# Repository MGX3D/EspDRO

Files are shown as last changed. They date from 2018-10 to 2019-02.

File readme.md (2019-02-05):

EspDRO - ESP32 DIY Digital Readout
----

EspDRO reads and proxies data from SPC capable (serial) digital calipers and indicators without any additional electronic components but using instead the built-in ADC in ESP32. It enables building custom, high-resolution measuring instruments, fully capable DRO (Digital Readout) panels for CNC/3D Printers, upgrade open-loop robots to closed-loop, point cloud 3D scanners, etc.

It costs $10-$20 to build (excluding instruments and time) and it's only 500 lines of code - it's amazing how powerful and affordable IoT chips (like ESP32) have become. 

Overview:
---
- Reads and re-transmits the instrumet data over multiple channels:
    - **WebSockets broadcasting**: allows building simple, low latency clients (10 lines of code Python sample [PyDRO](examples/PyDRO/) included as well as JavaScript/HTML [jsDRO](/examples/jsDRO) )
    - **Built-in web server**:  allows reading the data from browser/phone/tablet without any additional apps. Big display!
    - **REST APIs** and mDNS support: to build thin client apps easily
    - **USB serial**: for running without WiFi
        
- Protocol and interfacing:
    - ESP32 reads the 1.5V SPC signal via the ADC in ESP32, therefore **no additional level shifting electronic components necessary**
    - **Automatic baud rate**: it reads as fast as the instrument can transmit, in practice however most cheap devices seem to send packets at 8-10Hz
    - **Built-in 4KB buffer** for historical reads - easy to extend if there is free memory on the chip
    - Data is read on a separate thread to avoid packet loss (can be moved on a different CPU core in ESP32)

- Other (fine touches):
    - **Automatic Access Point -> Client mode**: Includes WiFi setup page and saves credentials in EEPROM, so it does not need to be reflashed when going to a different location
    - **Automatic units conversion**: EspDRO works only with microns internally which means readings remain constant even if you change the units SAE<->metric while you measure. Keeps things simple.
    - **Self-documented Pinout**: for those instances when wires come loose and memory doesn't help
    - **mDNS advertising**: allows instrument names to be decoupled from knowing IP address
    - **3D Printable SPC connector** ([also onthingiverse](https://www.thingiverse.com/thing:3141366)): 
        - All you need is 3 wires to make a SPC connector (4 wires if you want to power the instrument from ESP32, example using AMS1117 1.5v voltage regulator)
        - Tested to work on both calipers and indicators (slightly different commercial connectors).

**Web view**

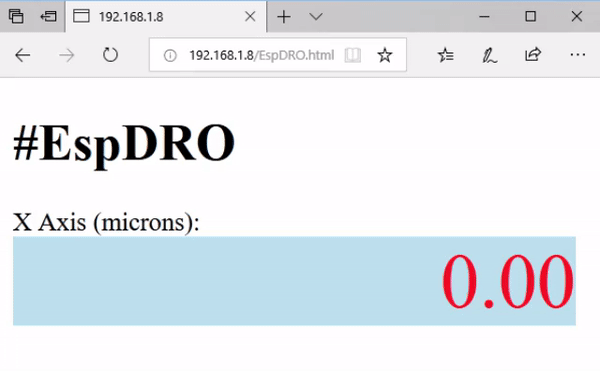
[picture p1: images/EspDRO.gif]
EspDRO


**Schematic**

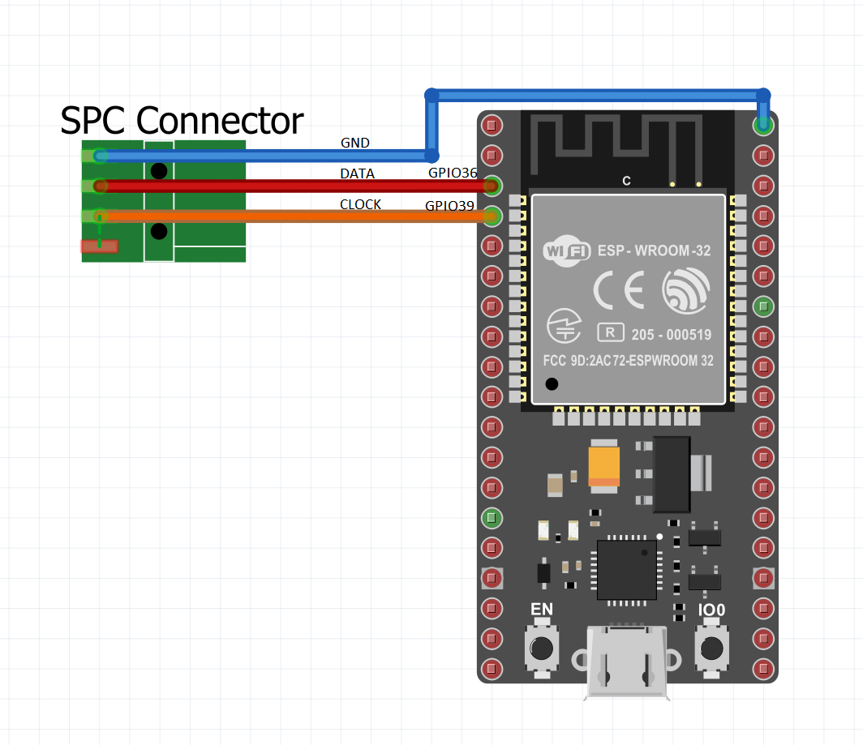
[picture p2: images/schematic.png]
schematic


**Video of it in action**

video (https://www.youtube.com/watch?v=P8z91OxXOTo)

Background:
----
This project started with my need to diagnose the positioning errors in one of my 3D printers: I had both 1-micron and 10-micron resolution indicators and calipers but measuring manually (write down readings from the instrument LCD) would have taken way too much time and effort. Since I had an ESP32 laying around, I figured I'd give that a try and I was amazed how easy it was to automate the whole thing: command the 3D printer via G-Code, then read the calipers/indicator via ESP32. Of course that in the process of building the instrument people seeing the data started asking for the firmware, so I decided to put some "finishing touches" (yeah, that really means 10x more lines of code :) ) and publish it, but also as a PIF for others that have posted useful guides around this space and helped me build this quickly. That's how #EspDRO came up.

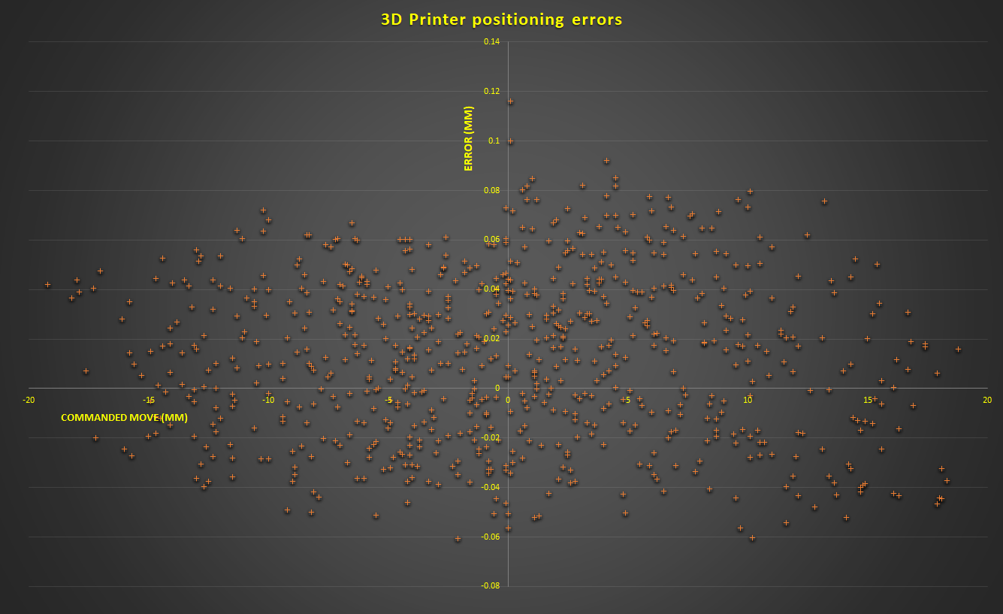
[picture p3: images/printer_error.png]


Installation:
----
_Software prerequisites_:

Arduino IDE (1.8.6) with [ESP32 support](https://github.com/espressif/arduino-esp32), including [esp32fs filesystem uploader plugin](https://github.com/me-no-dev/arduino-esp32fs-plugin) 

_Hardware prerequisites_:
- Espressif ESP32. The particular board this firmware was developed with is this (if yours is different, adjust dataPin and clockPin in the source): 
    - 
- SPC serial cable: if you don't have one you can use the [3D printable connector](CAD/spc_connector.stl), see [thingiverse page](https://www.thingiverse.com/thing:3141366) for more info. 
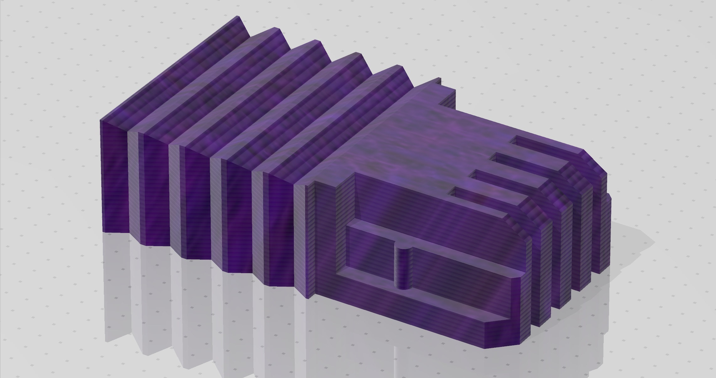
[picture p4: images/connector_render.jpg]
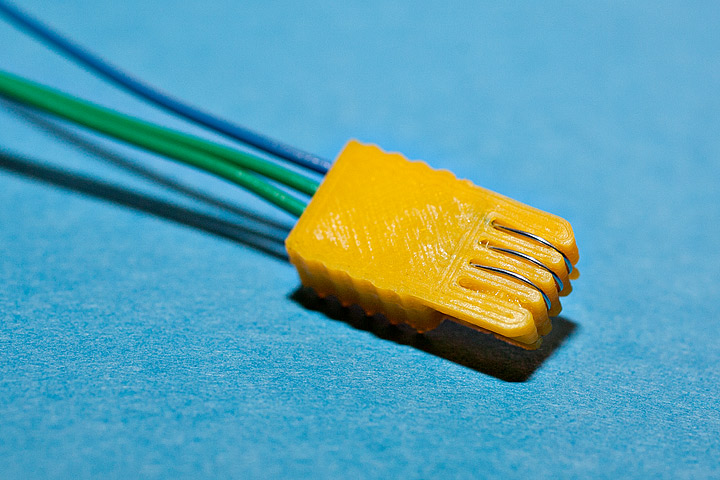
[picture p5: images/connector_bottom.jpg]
    -  
- Digital scale, calipers or DRO matching the connector. Examples:
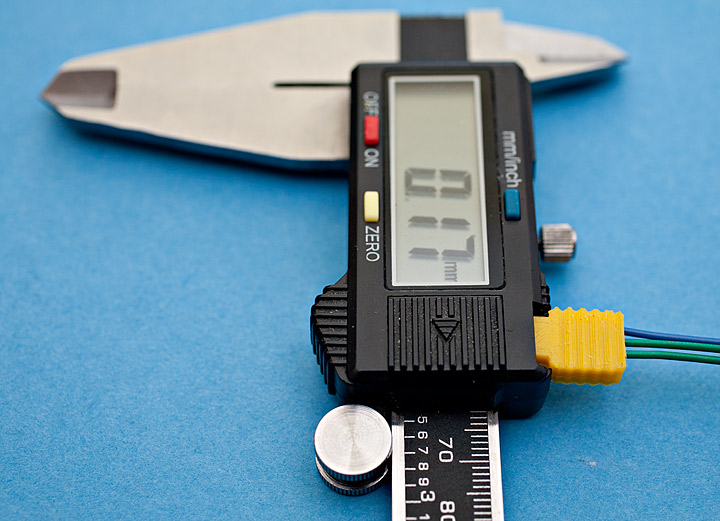
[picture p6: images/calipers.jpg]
caliper
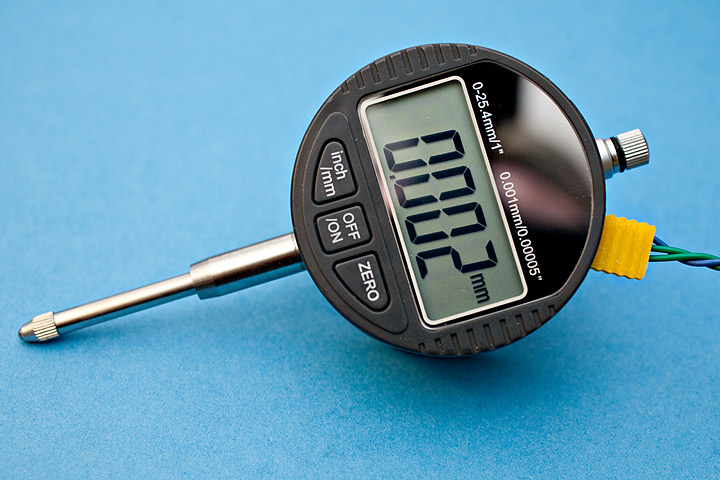
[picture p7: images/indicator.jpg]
indicator
    -  

Validate the cable works and the pinout in the firmware is correct. If you have an oscilloscope, the signal should look like this:
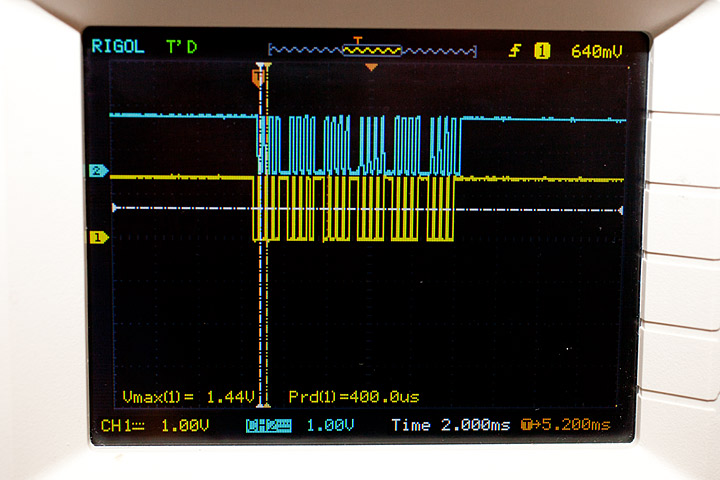
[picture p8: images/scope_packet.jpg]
scope packet
- 

Flash the webserver files (Tools->ESP32 Sketch Data Upload) and then upload the sketch/firmware. Start the serial monitor and you should see something like this:
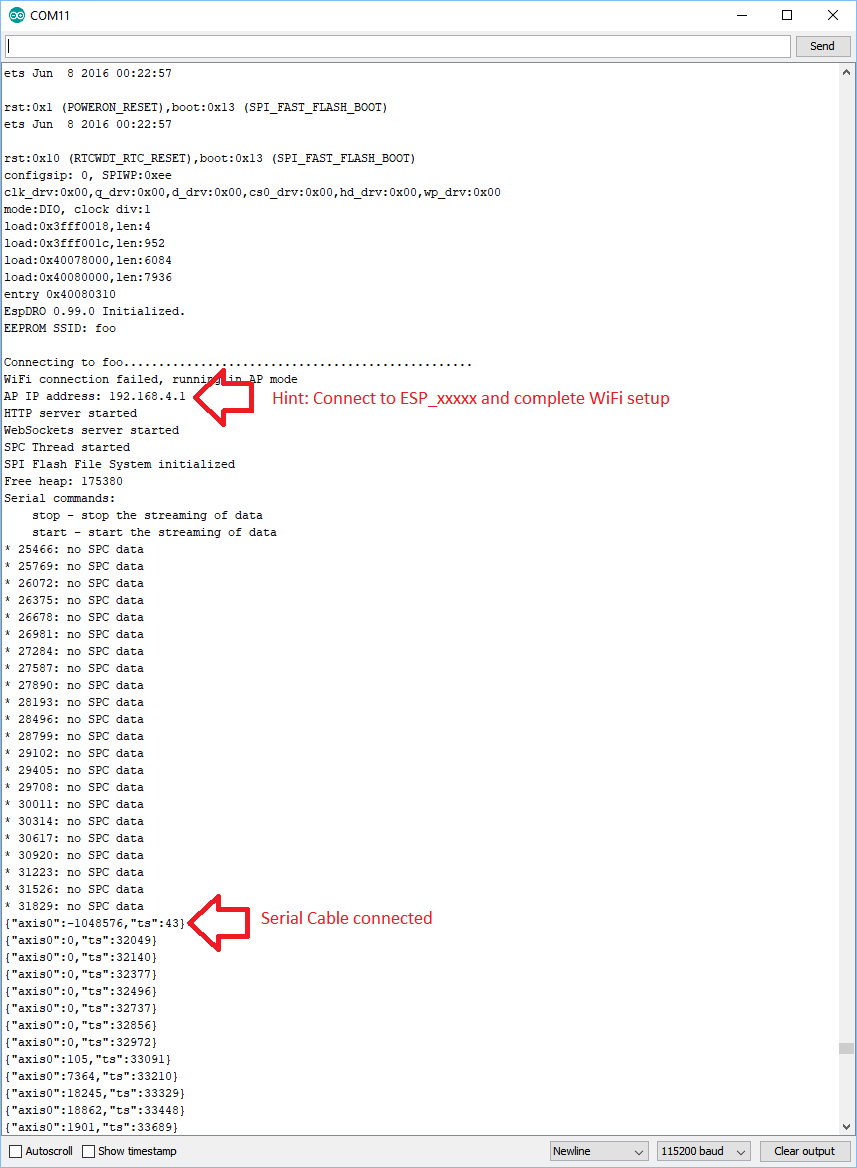
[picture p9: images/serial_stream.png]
serial monitor
- 

Note: If you don't have an oscilloscope and the data is not coming through, there is a 'debug' serial command which you can use to calibrate the Analog Digital Converter. This will also tell you if the pins on ESP32 are actually getting any analog data, as different dev boards have the ADC1_0 and ADC1_3 pins mapped differently than DevKitC above.

Now navigate to the main page and set up WiFi:
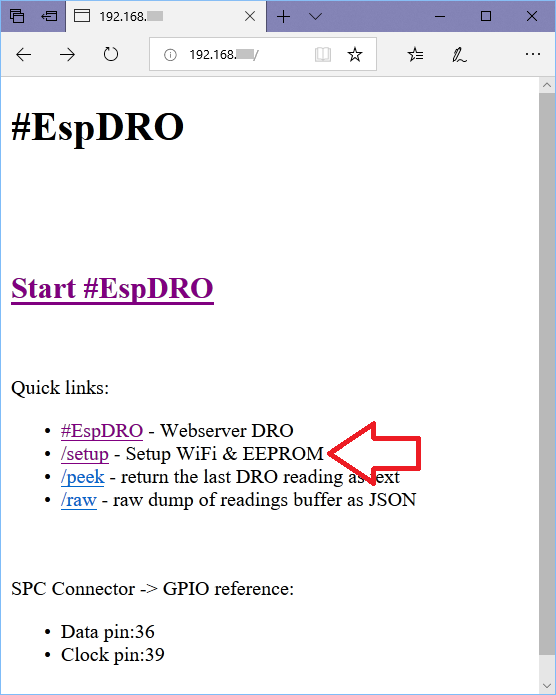
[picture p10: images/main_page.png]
main page
- 
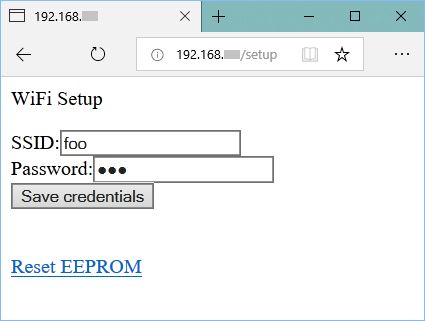
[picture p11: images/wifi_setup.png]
wifi setup
- 

Future plans (opportunities for contributors):
---
- **Multi-Axis**: Currently only one instrument supported but it's possible to extend EspDRO to multi-axis ($TODO, soon)
- **Time-of-Flight sensors**: One thing I'm really eager to add is [VL53L0X](https://www.st.com/resource/en/datasheet/vl53l0x.pdf) Time-of-Flight sensor, this should be able to read at 15-50Hz and +/-3% accuracy and without touching (influencing) the measured object. 
- **TTL glass scale**:  these are more expensive devices used in large mill DROs and can have 0.5-5 microns accuracy and extreme lengths (1+ meters)
- **Mill DRO functions**: implement common functions in DRO (find mid-point, center of circle, create hole patterns, datum points, absolute/incremental, memory, units conversion, etc)
- **Live charting**: 1-3 axis charting directly built-in the web console: for example to build a print bed mesh map (or 2.5D/3D point cloud) or axis error scatter plot 
- **Bluetooth support**: since ESP32 has BT, why not add a 5th interface?
- **Digital micrometer support**: Dicfeos and similar are affordable and micron-level accuracy - connector is different and can't be 3D printed. Less of a priority, as these require manual operation to measure.

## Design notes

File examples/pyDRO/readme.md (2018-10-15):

Sample Python client for EspDRO

It reads the data via websocket and prints it on console.

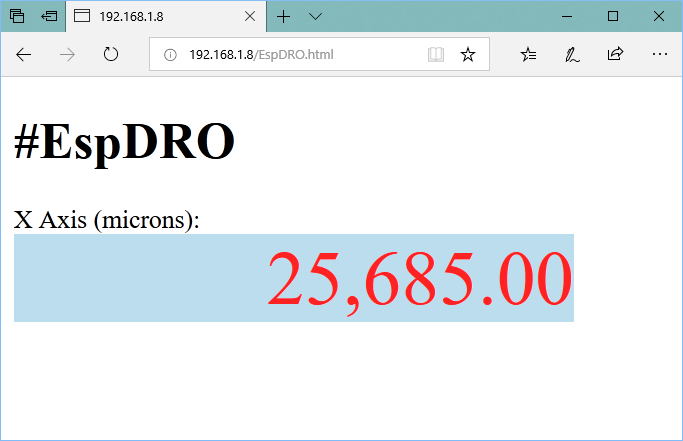
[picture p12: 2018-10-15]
images/esp_dro.png

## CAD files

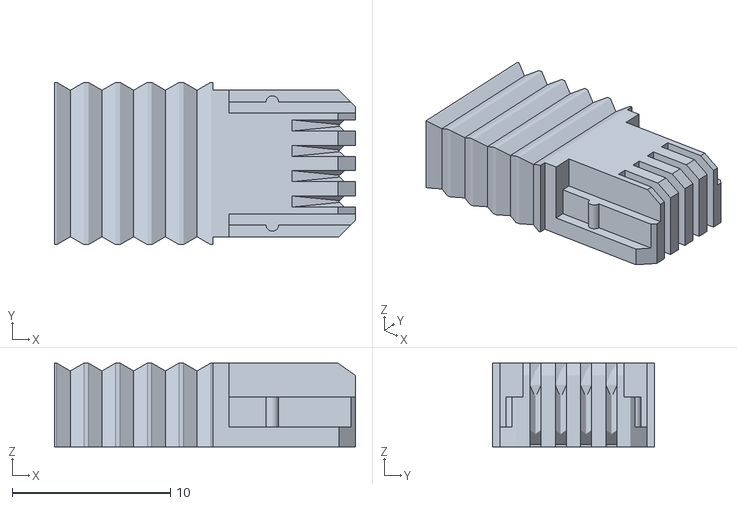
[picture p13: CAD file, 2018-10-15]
CAD/spc_connector.stl
19.0 x 10.2 x 5.30

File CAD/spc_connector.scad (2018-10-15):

// SPC serial connector wire guide. 
// Design by Marius Gheorghescu, Oct 2018
//
// Suggested print settings: flexible filament, 0.15mm layer height
//

// bottom to top
top_height = 5.3;
top_width = 6.4;

clip_height = 3.15;
clip_width = 7.75;

base_height = 1.25;
base_width = 9.25;

connector_depth = 8;

retention_clip_depth = 2.75;
retention_clip_radius = 0.4;

epsilon = 0.001;

pin_spacing = 1.6;

pin_depth = 0.5;
pin_width = 0.75;

pin_spacing_connector = 2.6;

module wire_connector()
{
    wire_dia_coated_x = 1.2;
    wire_dia_coated_z = 1.4;
    wire_dia = 0.7;
    wire_spacing_factor = 1.3;
    
    grip_depth = 10;
    
    difference() {

        $fn = 30;
        
        union() {
            
            // base
            translate([connector_depth/2,0,base_height/2])
                cube([connector_depth, base_width, base_height], center=true);

            // grip
            translate([-grip_depth/2 - 1,0, top_height/2])
                cube([grip_depth, base_width+1, top_height], center=true);
            
            translate([-grip_depth/2,0, top_height/2])
                cube([grip_depth, base_width, top_height], center=true);
            
            // mid-point block
            translate([connector_depth/2,0,clip_height/2])
                cube([connector_depth, clip_width, clip_height], center=true);

            // top block
            translate([connector_depth/2,0,top_height/2])
                cube([connector_depth, top_width, top_height], center=true);
            
            // retention clips
            color("red")
            translate([retention_clip_depth, clip_width/2, clip_height/2])
                cylinder(r=retention_clip_radius, h=clip_height, center=true);

            color("red")
            translate([retention_clip_depth, -clip_width/2, clip_height/2])
                cylinder(r=retention_clip_radius, h=clip_height, center=true);
        }
        
        // see-through cut-out
        // translate([-10,-10,0]) cube([20,20,20], center=true);

        // front chamfer 
        rotate([0,35,0])
        translate([connector_depth/2,0,top_height + top_height/2 + 1])
            cube([connector_depth, top_width+epsilon, top_height/4], center=true);
        

        // chamfer corners
        {
            translate([connector_depth, base_width, top_height/2 - epsilon])
            rotate([0,0,45])
            cube([connector_depth, base_width, top_height], center=true);

            translate([connector_depth, -base_width, top_height/2 - epsilon])
            rotate([0,0,-45])
            cube([connector_depth, base_width, top_height], center=true);
        }        

        // ribs
        for(i=[1:2:grip_depth]) {
            translate([-1-i,-base_width/2-1,top_height/2])
                rotate([0,0,-30])
                cylinder(r=1, h=top_height+epsilon, $fn=6, center=true);

            translate([-1-i,base_width/2+1,top_height/2])
                rotate([0,0,30])
                cylinder(r=1, h=top_height+epsilon, $fn=6, center=true);


            translate([-1-i,0,top_height+0.5])
            rotate([0,90,90])
                cylinder(r=1, h=base_width+2, $fn=6, center=true);
        }

        // pin contact area guide
        // translate([connector_depth - 2.45,0,0])%cube([2.40, 5.54, 1], center=true);
        
        for(i=[-1.5:1:1.5]) {

            // contact channels
            #translate([connector_depth/2, i*pin_spacing, 0])
                cube([connector_depth/2, pin_width, pin_depth], center=true);

            // top attach
            hull() {
            translate([connector_depth*0.75, i*pin_spacing, top_height - wire_dia_coated_z/2 + epsilon])
                cube([connector_depth/2, wire_dia, wire_dia_coated_z], center=true);

            translate([connector_depth*0.75, i*pin_spacing, top_height - wire_dia_coated_z/2 + epsilon])
                rotate([0,25,0])
                cube([connector_depth/2, 0.01, wire_dia_coated_z], center=true);
            }

            // slicer path width guide
            //translate([0, -top_width/2 + 0.2,0])
            //%color("blue", 0.2) cube([20, 0.4, top_height*1.5], center=true);

            // through wires
            translate([-connector_depth - epsilon, i*pin_spacing*wire_spacing_factor, top_height/2])
                cube([connector_depth, wire_dia_coated_x, wire_dia_coated_z], center=true);

            // front contact lift 
            translate([connector_depth - 1, i*pin_spacing, pin_depth/2 - epsilon])
                rotate([0,-35,0])
                cube([connector_depth, wire_dia, 2*pin_depth], center=true);

            // wire front channel
            hull() {
                translate([connector_depth - wire_dia/2 + epsilon, i*pin_spacing, 0])
                    cube([wire_dia, wire_dia, wire_dia], center=true);

                hull() {
                    translate([connector_depth - wire_dia/2 + epsilon, i*pin_spacing, top_height/2])
                        cube([wire_dia, wire_dia, top_height], center=true);
                    translate([connector_depth - wire_dia/2 + epsilon, i*pin_spacing, top_height/2])
                        cube([wire_dia*2, 0.01, top_height], center=true);
                }
            }

            // back
            #hull() {
                translate([connector_depth/2, i*pin_spacing, 0])
                    cube([2*wire_dia, wire_dia, wire_dia], center=true);

                translate([-connector_depth/2, i*pin_spacing*wire_spacing_factor, top_height/2])
                    cube([wire_dia_coated_x, wire_dia_coated_x, wire_dia_coated_z], center=true);
            }

        }
    }
}

color("green")
    wire_connector();

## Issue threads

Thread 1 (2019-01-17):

Logging AP IP adress

pwe101, 2019-01-17:
Hi,
The logging of the AP IP adress does not work correctly, the code:
log("AP IP address: %s", WiFi.softAPIP().toString());
results in:
AP IP address: ⸮8⸮?
in the serial monitor

Adding
Serial.println(WiFi.softAPIP());
to the code does give a valid IP address.

Serial.println(WiFi.softAPIP().toString());
Also gives a valid IP address.

Closed 2019-01-19.

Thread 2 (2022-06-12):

ESPRO at 50Hz in stead of 3Hz

jeedee23, 2022-06-12:
This is a very nice project, and I was wondering if anyone has developed the 'FAST' mode DRO.
My plan is to use this DRO as a closed-loop system to drive spindles at a determined speed, the feedback of 50Hz or faster would be ok, but the feedback of 3 Hz is too slow.

The 50Hz functionality is already built-in in all of these calipers by means of the hidden 'mode' button: Activating the mode button switches back and forth between fast reading and regular reading modes.  The scale updates about every 20ms (50 Hz) in fast reading mode instead of every 300ms (3 Hz).
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

Personally I would an interrupt to determine the 'getpacket' (which waits until the packet is completed by the getbit() function) . This means that the PACKET_READ_TIMEOUT would not matter anymore, since the complete packet is captured.  (it would have a purpose still to use it of course, but the value would be around 20 ms)
Then I would compare the new packet with the two previous ones to inspect for glitches
Then use ESPNOW to send the data to another MAINESP32 which takes care of the readout and send through the server, since the process would be to fast now, to be concerned with the whole handshaking, acknowledging etc.

The DROX-esp3E2 (X axis) DROY-esp32(Y-axis) would then adapt the position/speed they received from MAINESP32.

Somebody gone this far already?

MGX3D, 2022-06-12:
Interesting, I didn't know about this mode but it should be possible: ESP32 has a fast ADC mode via I2S, so it can go to 200KHz or more. It also have super high resolution (and low drift) clocks and timers via MCPWM if needed, but afaik (unlike STM32) the two cannot be synchronized on ESP32 (except by means of software tricks)

jeedee23, 2022-06-12:
Hi Marius,

Did not really understand what you mean. You mean the speed of readout or the speed for adjusting speeds (a sort of PID at first) following the readout.

We read the whole packet in a timespan of 20 ms (your PACKET_READ_TIMEOUT 250 ms )  the 'long' low time before and after the stream of bits not included. Changing the milliseconds to microseconds would be one of the first things to do.
After that, we need to use the time left to adjust speed and position of the spindle (once a PID is established, those values can be stored or transmitted at boot by the main computer (where the DRO will be displayed and the code is running giving the positions to go to). This it totally unlike steppers doing xxx steps to go to a position, no, it's giving a position and 'be there at that time at that speed'. By that means any motor can be used, supposed the resolution/speed/reaction time is physically possible, Th be clear, in this first setup, I'll be using DC gear motors with encoders (for redundancy, and also for backlash elimination)

I2S: you mean I2C?
Finally I would use one core of the ESP32 for readout and ESPNOW, the other one for motor control, they can work independently, so it should be perfectly possible.

I just don't know how to setup everything in microseconds, if you could give me a hint there, that would be a charm.

Oh yes, I rebuilt the calipers so they can read up to 1999,99 mm, ordered enough pcb (behind the masking tape, for 100 of those calipers)

Sartos, 2024-09-29:
> Ах да, я переделал штангенциркули так, чтобы они могли считывать показания до 1999,99 мм, заказал достаточно печатной платы (под малярной лентой, для 100 таких штангенциркулей)

Hello Johan. Could you tell me how to modify the calipers so that they read such large readings?

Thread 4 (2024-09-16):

randomic data

GlidLov, 2024-09-16:
Hi,

i've setup an esp32 with EspDRO as showed in readme (pins 36 and 39, and GND) with a standard  chinese 150mm caliper with the interface plug, and all i'm getting is randomic data. I tried to unplug and swapping pins with no success. Debug prompt shows data arrives, but numbers appears random, even when caliper is not moving at all.
What can i try? Do other ADC on esp32 works aswell?

PS i converted the SPIFF code into LittleFS code (trivial) since spiffs is not supported anymore. It works ok just swapping libs and changing SPIFFs occurrences.

Aleitao2, 2025-01-13:
Hello,
I am trying to implement that code. It runs smoothly, but I am getting random values as well. Did you find a solution? What hardware are you using, and how are you powering the caliper?
Did you use a level shifter for the data and clock signals?

In my case, I am using a resistor voltage divider and connecting the CLK and DAT pins directly to the ESP GPIOs 33 and 32.

I am using Arduino IDE v1.8.13, which allows you to use a tool to burn the data content. The tool I mentioned : https://github.com/me-no-dev/arduino-esp32fs-plugin

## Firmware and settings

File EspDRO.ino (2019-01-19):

#include <WiFiClient.h>
#include <WiFi.h>
#include <EEPROM.h>
#include <WebServer.h>
#include <ESPmDNS.h>
#include <WebSockets.h>
#include <WebSocketsServer.h>
#include <driver/adc.h>
#include <FS.h>
#include "SPIFFS.h"

#define ESPDRO_VERSION "0.99.1"

// WiFi configuration - can be changed via AP/EEPROM
const char* ssid = "EspDRO";
const char* password = "EspDRO";

// Note: this sketch requires the webserver files to be uploaded to ESP32 SPIFFS, see: https://github.com/me-no-dev/arduino-esp32fs-plugin

// Pin Configuration - !!! Update This !!! 
// Example pinout: https://raw.githubusercontent.com/gojimmypi/ESP32/master/images/myESP32%20DevKitC%20pinout.png
int dataPin = 36; // yellow
int clockPin = 39; // green

// ADC threshold for 1.5V SPCsignals (at 6dB/11-bit, high comes to around 1570 in analogRead() )
#define ADC_TRESHOLD 800

// define this to display the raw signal (useful to troubleshoot cable or signal level issues)
#define DEBUG_SIGNAL 0

// timeout in milliseconds for a bit read ($TODO - change to micros() )
#define BIT_READ_TIMEOUT 100

// timeout for a packet read 
#define PACKET_READ_TIMEOUT 250

// Packet format: [0 .. 19]=data, 20=sign, [21..22]=unused?, 23=inch
#define PACKET_BITS       24

// minimum reading
#define MIN_RANGE -(1<<20)

// DRO circular buffer entries (4096 entries is roughly the equivalent of 8 minutes of data)
#define DRO_BUFFER_SIZE  0x1000


// DRO 1-Reading class
struct Reading
{  
    uint32_t timestamp;
    int32_t microns;

    Reading(): timestamp(millis()), microns(MIN_RANGE)  {}

    Reading& operator=(const Reading& obj) {
      timestamp = obj.timestamp;
      microns = obj.microns;
      return *this;
    }    
};


// DRO circular buffer
Reading dro_buffer[DRO_BUFFER_SIZE] = {};
size_t dro_index = 0;

unsigned char eepromSignature = 0x5A;

bool client_mode = 1;
bool stream_mode = 1;
volatile bool debug_mode = 0;

WebServer server(80);
WebSocketsServer webSocket = WebSocketsServer(81);

void log(char *fmt, ... )
{  
  char buf[128];
  va_list args;
  va_start (args, fmt);
  vsnprintf(buf, 128, fmt, args);
  va_end (args);
  Serial.println(buf);
}

// capped read: -1 (timeout), 0, 1
int getBit() {
    int data;

    if (debug_mode) {
      // debug code to sample the data reads
      log("CLK:%6d DATA:%6d\n", analogRead(clockPin), analogRead(dataPin));
    }
        
    int readTimeout = millis() + BIT_READ_TIMEOUT;
    while (analogRead(clockPin) > ADC_TRESHOLD) {
      if (millis() > readTimeout)
        return -1;
    }
    
    while (analogRead(clockPin) < ADC_TRESHOLD) {
      if (millis() > readTimeout)
        return -1;
    }
    
    data = (analogRead(dataPin) > ADC_TRESHOLD)?1:0;
    return data;
}

// read one full packet
long getPacket() 
{
    long packet = 0;
    int readTimeout = millis() + PACKET_READ_TIMEOUT;

    int bitIndex = 0;
    while (bitIndex < PACKET_BITS) {
      int bit = getBit();
      if (bit < 0 ) {
        // bit read timeout: reset packet or bail out
        if (millis() > readTimeout) {
          // packet timeout
          return -1;
        }
        
        bitIndex = 0;
        packet = 0;
        continue;
      }

      packet |= (bit & 1)<<bitIndex;
      
      bitIndex++;
    }
    
    return packet;
}

// convert a packet to signed microns
long getMicrons(long packet)
{
  if (packet < 0)
    return MIN_RANGE;
    
  long data = (packet & 0xFFFFF)*( (packet & 0x100000)?-1:1);

  if (packet & 0x800000) {
        // inch value (this comes sub-sampled) 
        data = data*254/200;
  }

  return data;
}


void spcTask( void * parameter )
{
    uint32_t lastReadTime = millis();

    for(;;) { 
      long packet = getPacket();
      
      if (packet < 0) {
        // read timeout, display?
        if (millis() > lastReadTime + PACKET_READ_TIMEOUT) {
          // advance last read to time-out
          lastReadTime = millis();
          log("* %d: no SPC data", lastReadTime);
        }
      } else {

        // add to local queue
        //log("* %d: microns=%d raw=0x%08X", millis(), getMicrons(packet), packet);
        size_t new_dro_index = (dro_index+1) % DRO_BUFFER_SIZE;
        dro_buffer[new_dro_index].timestamp = millis();
        dro_buffer[new_dro_index].microns = getMicrons(packet);
        dro_index = new_dro_index;

        // broadcast to all websocket clients
        char buf[128];
        sprintf(buf, "{\"axis0\":%d,\"ts\":%d}", dro_buffer[new_dro_index].microns, dro_buffer[new_dro_index].timestamp);
        webSocket.broadcastTXT(buf);
      }
    } 
    //vTaskDelete( NULL ); 
}

void webSocketEvent(uint8_t num, WStype_t type, uint8_t * payload, size_t length) {

    switch(type) {
        case WStype_DISCONNECTED:
            log("[%u] Disconnected!\n", num);
            break;
            
        case WStype_CONNECTED:
            {
                log("[%u] Connected from %s url: '%s'\n", num, webSocket.remoteIP(num).toString().c_str(), payload);

                // send message to client
                webSocket.sendTXT(num, "Connected");
            }
            break;
            
        case WStype_TEXT:
            log("[%u] get Text: %s\n", num, payload);

            // send message to client
            // webSocket.sendTXT(num, "message here");

            // send data to all connected clients
            // webSocket.broadcastTXT("message here");
            break;
            
        case WStype_BIN:
            log("[%u] get binary length: %u\n", num, length);

            // send message to client
            // webSocket.sendBIN(num, payload, length);
            break;
            
    case WStype_ERROR:      
    case WStype_FRAGMENT_TEXT_START:
    case WStype_FRAGMENT_BIN_START:
    case WStype_FRAGMENT:
    case WStype_FRAGMENT_FIN:
      break;
    }

}

// root HTTP request - keep this in code in case there is any SPIFFS corruption
void handle_root() {
  String content = "<!DOCTYPE HTML>\r\n<html><body>";
  content += "<h1>#EspDRO</h1><br>";
  content += "<br><br><h2><a href=\"/EspDRO.html\">Start #EspDRO</a></h2><br><br>";
  content += "Quick links: <ul>";
  content += "<li><a href=\"/EspDRO.html\">#EspDRO</a> - Webserver DRO</li>";
  content += "<li><a href=\"/setup\">/setup</a> - Setup WiFi & EEPROM</li>";
  content += "<li><a href=\"/peek\">/peek</a> - return the last DRO reading as text</li>";
  content += "<li><a href=\"/raw\">/raw</a> - raw dump of readings buffer as JSON</li>";
  content += "</ul><br>";  
  content += "<br>SPC Connector -> GPIO reference:<br><ul><li>Data pin:" + String(dataPin) + "</li><li>Clock pin:" + String(clockPin) + "</li></ul><br>";
  content += "</body></html>";
  
  server.send(200, "text/html", content);
  delay(50);
}

// SPIFFS content type autodetect
String getContentType(String filename)
{
  if (filename.endsWith(".html")) return "text/html";
  else if (filename.endsWith(".css")) return "text/css";
  else if (filename.endsWith(".js")) return "application/javascript";
  else if (filename.endsWith(".png")) return "image/png";
  else if (filename.endsWith(".jpg")) return "image/jpeg";
  else if (filename.endsWith(".ico")) return "image/x-icon";
  return "text/plain";
}

// serve SPIFFS requests
bool handleFS(String path)
{
  if (SPIFFS.exists(path)) {
    File file = SPIFFS.open(path, "r");
    server.streamFile(file, getContentType(path));
    file.close();
    return true;    
  }
  log("Error in SPIFFS request: '%s", path.c_str());
  return false;
}

void setup()
{
  pinMode(dataPin, INPUT);     
  pinMode(clockPin, INPUT);

  EEPROM.begin(512);
  delay(20);

  Reading start_reading;
  dro_buffer[dro_index] = start_reading;

  Serial.begin(115200);
  log("EspDRO %s initialized.", ESPDRO_VERSION);

  analogReadResolution(11);
  
  analogSetAttenuation(ADC_6db);
  adc1_config_width(ADC_WIDTH_BIT_10);

  String essid = ssid;
  String epassword = password;
  
  if (client_mode) 
  {
    // attempt WiFi client mode
    essid = "";
    epassword = "";

    if (EEPROM.read(128) != eepromSignature) {
      log("EEPROM not initialized");
    } else {
      for (int i = 0; i < 32; ++i)
      {
        essid += char(EEPROM.read(i));
      }
      
      log("EEPROM SSID: %s", essid.c_str());
      for (int i = 32; i < 96; ++i)
      {
        epassword += char(EEPROM.read(i));
      }
    }

    if (essid.length() > 0) {
      // connect to EEPROM settings
    } else {
      // connect to hardcoded wifi
      essid = ssid;
      epassword = password;
    }
    
    log("\n\rConnecting to '%s'", essid.c_str());
    WiFi.begin(essid.c_str(), epassword.c_str());
  
    int retries=50;
    while ((WiFi.status() != WL_CONNECTED) && (retries-- > 0)) {
      delay(500);
      Serial.print(".");
    }
    log("\n");
  }
  
  if (WiFi.status() == WL_CONNECTED) {    
    log("\nConnected to '%s', IP: %s", essid.c_str(), WiFi.localIP().toString().c_str());

    if (!MDNS.begin("EspDRO")) {
      log("Error setting up MDNS responder.");
    } else {
      log("MDNS responder started");
    }
    
  } else {
      // fall-back to AP mode for setup
      log("WiFi connection failed, running in AP mode\n");
      WiFi.softAP(ssid, password);
  
      log("AP IP address: %s", WiFi.softAPIP().toString().c_str());
  }

  server.on("/", handle_root);

  server.on("/peek", [](){    
    String webString = String(dro_buffer[dro_index].microns);
    server.send(200, "text/plain", webString); 
    delay(50);
  });

  server.on("/raw", [](){      
    unsigned int ts = 0;

    // ?ts=<micros> - 
    if(server.hasArg("ts")) {
      ts = server.arg("ts").toInt();
    }

    String rawJSON;
    for(size_t offset = 1; offset <= DRO_BUFFER_SIZE; offset++) {
      if (dro_buffer[(dro_index + offset) % DRO_BUFFER_SIZE].microns != MIN_RANGE) {
        rawJSON += "{\"axis0\":";
        rawJSON +=  dro_buffer[(dro_index + offset) % DRO_BUFFER_SIZE].microns;
        rawJSON += ",\"ts\":";
        rawJSON += dro_buffer[(dro_index + offset) % DRO_BUFFER_SIZE].timestamp;
        rawJSON += "}";
        yield();
      }
      //snprintf(buf, sizeof(buf), "{%d, %d}", dro_buffer[(dro_index + offset) % DRO_BUFFER_SIZE].timestamp, dro_buffer[(dro_index + offset) % DRO_BUFFER_SIZE].microns);
      //log(buf);
    }
    server.send(200, "text/plain", rawJSON);

  });

  server.on("/setup", [](){
    String content = "<!DOCTYPE HTML>\r\n<html>";
    content += "WiFi Setup<br></p><form method='get' action='settings'><label>SSID:</label><input name='ssid' length=32><br><label>Password:</label><input name='password' type=\"password\" length=64><br><input type=\"submit\" value=\"Save credentials\"></form><br><br><a href=\"/settings&reset=1\">Reset EEPROM</a></html>";
    server.send(200, "text/html", content);
  });
  
  server.on("/settings", [](){
    String lssid = server.arg("ssid");
    String lpassword = server.arg("password");
    String reset = server.arg("reset");
    if (lssid.length() > 0 && lpassword.length() > 0) {
      log("Clearing eeprom...\n");
      for (int i = 0; i < 96; ++i) {
          EEPROM.write(i, 0);
      }
      
      for (int i = 0; i < lssid.length(); ++i)
      {
        EEPROM.write(i, lssid[i]);
      }
                  
      for (int i = 0; i < lpassword.length(); ++i)
      {
        EEPROM.write(32+i, lpassword[i]);
      }

      EEPROM.write(128, eepromSignature);
      EEPROM.commit();
      log("EEPROM saved.\n");
      
      server.send(200, "application/json", "{\"Success\":\"WiFi settings saved to EEPROM. Reset to apply.\"}");
    }
    else if (reset.length() > 0) {
      log("Clearing EEPROM...\n");
      for (int i = 0; i < 96; ++i) {
        EEPROM.write(i, 0);
      }

      EEPROM.write(128, ~eepromSignature);      
      EEPROM.commit();
      
      server.send(200, "application/json", "{\"Success\":\"EEPROM settings cleared.\"}");
    } else {
      server.send(404, "application/json", "{\"Error\":\"404 not found\"}");
    }
  });
              
  server.begin();
  log("HTTP server started");

  webSocket.begin();
  webSocket.onEvent(webSocketEvent);  
  log("WebSockets server started");

  xTaskCreate(spcTask, "spcTask", 10000, NULL, 1, NULL); 
  log("SPC Thread started\n");

  SPIFFS.begin();
  log("SPI Flash File System initialized\n");

  server.onNotFound([]() {
    if (!handleFS(server.uri()))
      server.send(404, "text/plain", "404: Not Found (forgot to upload SPIFFS data?)");
  });
   
  log("Free heap: %u", ESP.getFreeHeap());

  log("Serial commands:\n    stop - stop the streaming of data\n    start - start the streaming of data\n    debug - turn on/off ADC signal debugging\n");
}


size_t last_dro_index = 0;
void loop()
{
  server.handleClient();
  webSocket.loop();

  if(Serial.available() > 0)
  {
      String serial_cmd = Serial.readStringUntil('\n');
      log("Received: cmd='%s'", serial_cmd.c_str());

      if (serial_cmd.startsWith("stop")) {
        // serial_cmd.substring(14).toInt();
        stream_mode = 0;
      } else if (serial_cmd.startsWith("start")) {
        stream_mode = 1;
      } else if (serial_cmd.startsWith("debug")) {
        debug_mode = !debug_mode;
      }
  }

  // async dump the DRO stream over serial
  if (stream_mode && (last_dro_index != dro_index)) {
      log("{\"axis0\":%d,\"ts\":%d}", dro_buffer[last_dro_index].microns, dro_buffer[last_dro_index].timestamp);
      last_dro_index = (last_dro_index+1) % DRO_BUFFER_SIZE;
  }
}

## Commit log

2018-10-15 Initial version
    [spc_connector.scad, spc_connector.stl]
2018-10-17 Added "schematic"
2019-01-19 fixed #1 - show correct softAP IP
    [EspDRO.ino]
2019-10-14 use mDNS name instead of hardcoded IP. Updated Python sample for async IO and json decoding
